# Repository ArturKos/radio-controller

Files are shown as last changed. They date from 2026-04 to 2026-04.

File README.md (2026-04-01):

# Radio Controller

A **433MHz RF light controller** built with an **ESP8266** (NodeMCU v2) and **CC1101** transceiver, managed through **ESPHome** and integrated with **Home Assistant**. Controls bedroom and living room lights over **ASK/OOK** modulation using captured RC Switch codes, with **Amazon Alexa** voice control via emulated_hue. Also functions as a passive **RF signal monitor**, logging all received 433MHz transmissions for discovering nearby weather stations, door sensors, and other devices. Includes a parametric **3D printable case** designed in **OpenSCAD**.








## Hardware

| NodeMCU v2 (ESP8266) | CC1101 RF Transceiver (433MHz) |
|:---:|:---:|
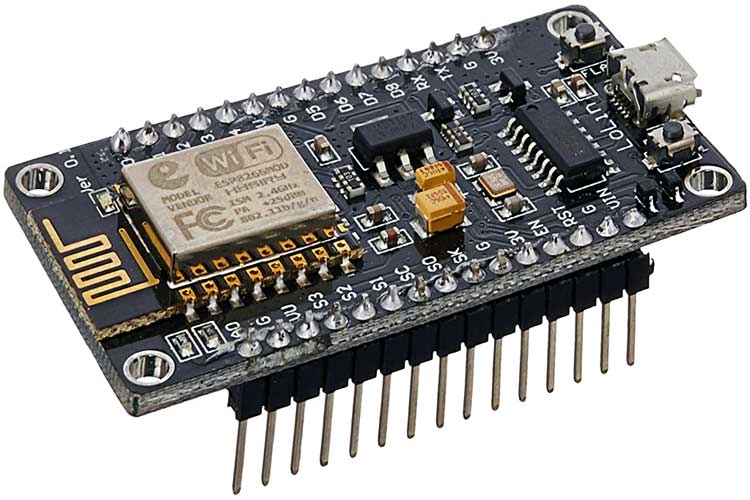
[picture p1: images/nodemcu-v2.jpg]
NodeMCU v2
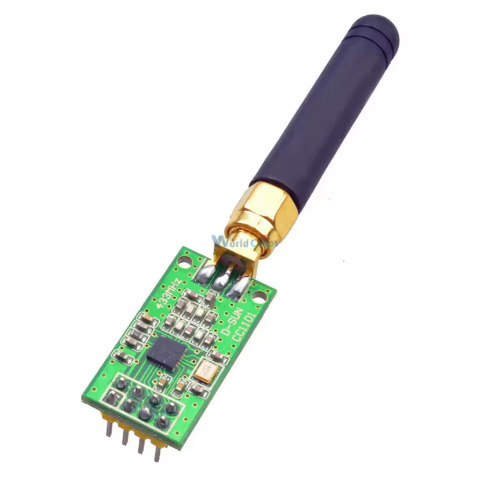
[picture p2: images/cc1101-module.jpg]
CC1101 Module
|  |  |

| Component | Details |
|---|---|
| MCU | NodeMCU ESP8266 v2 (nodemcuv2) |
| RF Transceiver | CC1101 with SMA antenna |
| Protocol | 433.92 MHz ASK/OOK |
| Integration | Home Assistant via ESPHome native API |
| Voice control | Amazon Alexa via emulated_hue |

## Wiring (SPI)

| CC1101 Pin | NodeMCU Pin | Function |
|---|---|---|
| SCK | D5 (GPIO14) | SPI Clock |
| MISO | D6 (GPIO12) | SPI Data Out |
| MOSI | D7 (GPIO13) | SPI Data In |
| CSN | D8 (GPIO15) | Chip Select |
| GDO0 | D2 (GPIO4) | RX + TX (shared) |
| GDO2 | D1 (GPIO5) | Connected, unused |
| VCC | 3.3V | Power (NOT 5V!) |
| GND | GND | Ground |

> **Note:** GDO0 is shared for both receiving and transmitting via `allow_other_uses: true`. The CC1101 native component switches between RX/TX modes automatically using `cc1101.begin_tx` / `cc1101.begin_rx` triggers.

## Features

- **Bedroom lights** (protocol 1) — Toggle, ON, OFF via HA buttons and Alexa voice commands
- **Living room lights** (protocol 3) — 8 buttons: toggle, on, off, timers (30s/30min/60min)
- **RF monitoring** — Counts received signals, logs all codes for device discovery
- **Noise filtering** — Protocol 2 code=0x0 spurious signals filtered out in lambda
- **WiFi hardening** — `fast_connect`, `power_save_mode: none`, max TX power for stable connection
- **3D printable case** — Parametric OpenSCAD enclosure with SMA antenna pass-through

## Architecture

```
┌──────────┐     SPI      ┌────────┐    433MHz    ┌──────────────┐
│ NodeMCU  │◄────────────►│ CC1101 │◄────────────►│ RF Lights    │
│ ESP8266  │              │  TX/RX │              │ (bedroom,    │
└────┬─────┘              └────────┘              │  living room)│
     │ WiFi                                       └──────────────┘
     ▼
┌──────────┐  emulated_hue  ┌───────┐
│  Home    │◄──────────────►│ Alexa │
│Assistant │                └───────┘
└──────────┘
```

## Setup

### 1. Prerequisites

- [ESPHome](https://esphome.io/) 2025.12.0+ (native CC1101 support)
- Home Assistant with ESPHome addon
- NodeMCU with ESPHome already flashed

### 2. Configure secrets

Copy and edit the secrets file:
```bash
cp secrets.yaml.example secrets.yaml
# Edit with your actual WiFi password, API key, etc.
```

### 3. Deploy

Upload config to HA and flash via ESPHome dashboard:
```bash
scp radio-controller.yaml ha:/homeassistant/esphome/radio-controller.yaml
```
Then open ESPHome dashboard in HA and click Install → Wirelessly.

### 4. Sniff RF codes

Open ESPHome logs and press buttons on your RF remotes. Look for entries like:
```
[rf_monitor] RC Switch: protocol=1 code=0x353FC0
```

### 5. Alexa integration

Bedroom lights are exposed via `emulated_hue` through `input_boolean.bedroom_light` in HA with automations that trigger the ESPHome button presses.

## RF Signal Discovery

The device logs all received 433MHz signals for identifying nearby devices (weather stations, door sensors, etc.):
- **Counter sensor** — "RF Signals Received" tracks daily activity (resets at midnight)
- **Last code sensor** — "Last RF Code" shows the most recent protocol + code
- Repeating codes every 30-60s are likely weather stations
- Codes appearing on events (door open/close) are likely contact sensors

## 3D Printed Case

Parametric OpenSCAD enclosure in `case/radio-controller-case.scad`. Fits NodeMCU v2 + CC1101 with SMA antenna.

| Assembled preview | Print layout (bottom + lid) |
|:---:|:---:|
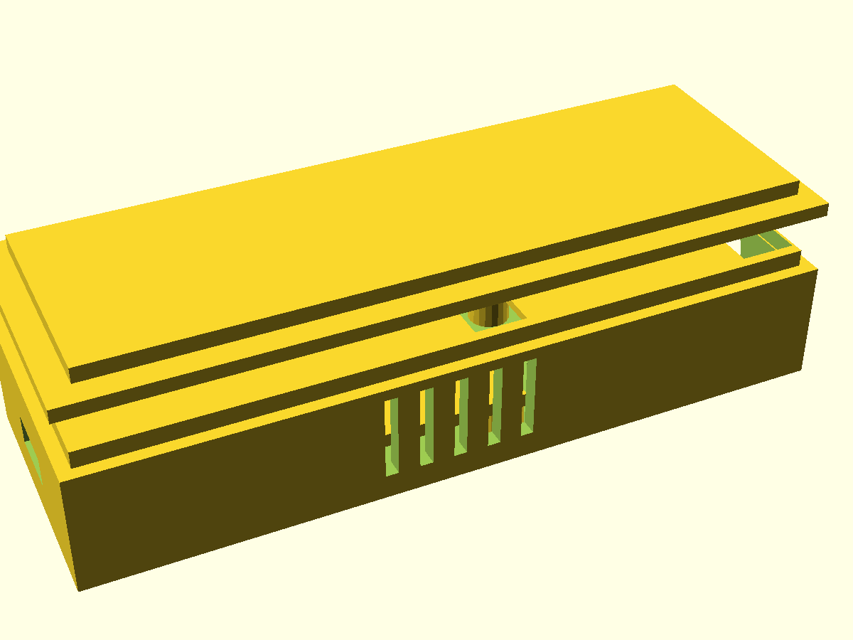
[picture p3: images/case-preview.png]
Case preview
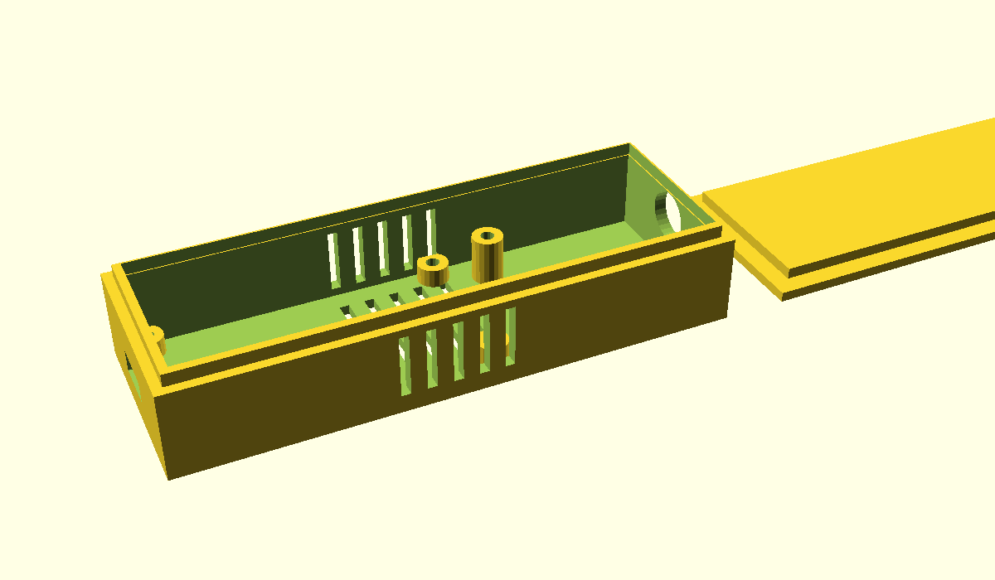
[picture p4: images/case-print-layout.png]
Print layout
|  |  |

- Mounting posts for both boards (M2 screws)
- Micro-USB cutout for power/programming
- SMA antenna hole for external antenna
- Snap-fit lid with alignment lip
- Ventilation slots on bottom, top, and sides
- No supports needed — print bottom and lid flat

Open in [OpenSCAD](https://openscad.org/), set `mode = "preview"` to see assembled view or `"print"` for print layout. Adjust `tol` parameter for your printer.

## Project Structure

```
radio-controller/
├── radio-controller.yaml          # ESPHome configuration
├── secrets.yaml                   # WiFi/API credentials (git-ignored)
├── case/
│   └── radio-controller-case.scad # 3D printable enclosure (OpenSCAD)
├── HOWTO.md                       # Development notes
└── README.md
```

## Known Issues

- **Living room lights** (protocol 3) — TX codes captured but lights don't respond; original remote also broken, likely receiver pairing issue
- **Protocol 2 noise** — RF interference generates ~2-3 spurious protocol 2 code=0x0 signals per minute; filtered in lambda
- **WiFi signal** — Marginal at -65 to -74 dBm; mitigated with `power_save_mode: none` and max TX power

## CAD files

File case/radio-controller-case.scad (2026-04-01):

// =============================================================================
// Radio Controller Case — NodeMCU v2 + CC1101 (SMA antenna)
// 3D printable enclosure, no supports needed
// Print: bottom + lid separately, flat side down
// =============================================================================

// --- Tolerances & print settings ---
tol       = 0.3;    // printer tolerance (adjust for your printer)
wall      = 2.0;    // wall thickness
floor_t   = 1.6;    // floor/ceiling thickness
post_d    = 5.0;    // mounting post diameter
screw_d   = 2.2;    // M2 screw hole diameter
snap_gap  = 0.2;    // lid snap-fit clearance

// --- NodeMCU v2 dimensions ---
nmc_l     = 49.0;   // length (USB to antenna end)
nmc_w     = 26.0;   // width
nmc_h     = 10.0;   // height with pins soldered underneath
nmc_pcb_t = 1.6;    // PCB thickness
nmc_usb_w = 8.0;    // micro-USB connector width
nmc_usb_h = 3.5;    // micro-USB connector height

// --- CC1101 module dimensions ---
cc_l      = 29.0;   // length (SMA end to opposite)
cc_w      = 20.0;   // width
cc_h      = 3.5;    // height (tallest component on PCB)
cc_pcb_t  = 1.0;    // PCB thickness
sma_d     = 6.5;    // SMA connector diameter (nut flats ~8mm)
sma_hole  = 8.0;    // SMA hole in wall (clearance for nut)

// --- Internal layout ---
gap       = 4.0;    // gap between NodeMCU and CC1101
wire_ch   = 3.0;    // wire channel depth

// --- Computed internal dimensions ---
int_l     = nmc_l + gap + cc_l + 2*tol;
int_w     = max(nmc_w, cc_w) + 2*tol;
int_h     = nmc_h + 2 + 2*tol;   // +2 for clearance above tallest component

// --- Computed external dimensions ---
ext_l     = int_l + 2*wall;
ext_w     = int_w + 2*wall;
ext_h_bot = floor_t + int_h;      // bottom half height
ext_h_lid = floor_t + 3;          // lid height (shallow)
lip_h     = 2.0;                  // lid inner lip height

// --- Vent hole settings ---
vent_w    = 1.5;
vent_gap  = 2.5;
vent_n    = 5;

// --- NodeMCU position (USB end at -X wall) ---
nmc_x     = wall + tol;
nmc_y     = wall + tol + (int_w - nmc_w)/2;

// --- CC1101 position (SMA end at +X wall) ---
cc_x      = wall + tol + nmc_l + gap;
cc_y      = wall + tol + (int_w - cc_w)/2;

// --- Mounting post positions ---
// NodeMCU: 4 corner posts, inset 2mm from edges
nmc_post_inset = 2.0;
nmc_posts = [
    [nmc_x + nmc_post_inset,               nmc_y + nmc_post_inset],
    [nmc_x + nmc_l - nmc_post_inset,       nmc_y + nmc_post_inset],
    [nmc_x + nmc_post_inset,               nmc_y + nmc_w - nmc_post_inset],
    [nmc_x + nmc_l - nmc_post_inset,       nmc_y + nmc_w - nmc_post_inset],
];

// CC1101: 2 posts on the non-SMA end
cc_post_inset = 2.0;
cc_posts = [
    [cc_x + cc_post_inset,                 cc_y + cc_post_inset],
    [cc_x + cc_post_inset,                 cc_y + cc_w - cc_post_inset],
];


// =============================================================================
// BOTTOM HALF
// =============================================================================
module bottom() {
    difference() {
        union() {
            // Main box
            difference() {
                // Outer shell
                cube([ext_l, ext_w, ext_h_bot]);

                // Inner cavity
                translate([wall, wall, floor_t])
                    cube([int_l, int_w, int_h + 1]);
            }

            // Mounting posts for NodeMCU
            for (p = nmc_posts) {
                translate([p[0], p[1], floor_t])
                    cylinder(d=post_d, h=3, $fn=20);
            }

            // Mounting posts for CC1101
            for (p = cc_posts) {
                translate([p[0], p[1], floor_t])
                    cylinder(d=post_d, h=nmc_h - cc_h + 1, $fn=20);
            }

            // Lid alignment rim (inner lip for lid to sit on)
            difference() {
                translate([wall - 0.5, wall - 0.5, ext_h_bot])
                    cube([int_l + 1, int_w + 1, lip_h]);
                translate([wall + 0.8, wall + 0.8, ext_h_bot - 0.1])
                    cube([int_l - 0.6, int_w - 0.6, lip_h + 0.2]);
            }
        }

        // --- Cutouts ---

        // Micro-USB port (NodeMCU, -X wall)
        translate([-0.1, nmc_y + nmc_w/2 - nmc_usb_w/2, floor_t + 3])
            cube([wall + 0.2, nmc_usb_w, nmc_usb_h]);

        // SMA antenna hole (CC1101, +X wall)
        translate([ext_l - wall - 0.1, cc_y + cc_w/2, floor_t + nmc_h - cc_h + cc_pcb_t + 1])
            rotate([0, 90, 0])
                cylinder(d=sma_hole, h=wall + 0.2, $fn=30);

        // Screw holes in mounting posts
        for (p = nmc_posts) {
            translate([p[0], p[1], -0.1])
                cylinder(d=screw_d, h=floor_t + 4, $fn=16);
        }
        for (p = cc_posts) {
            translate([p[0], p[1], -0.1])
                cylinder(d=screw_d, h=floor_t + nmc_h, $fn=16);
        }

        // Bottom ventilation slots
        translate([ext_l/2 - (vent_n*(vent_w + vent_gap))/2, ext_w/2 - 10, -0.1])
            for (i = [0:vent_n-1])
                translate([i * (vent_w + vent_gap), 0, 0])
                    cube([vent_w, 20, floor_t + 0.2]);

        // Side ventilation slots (both long sides)
        for (side = [0, ext_w - wall]) {
            translate([ext_l/2 - (vent_n*(vent_w + vent_gap))/2, side - 0.1, floor_t + int_h/2 - 5])
                for (i = [0:vent_n-1])
                    translate([i * (vent_w + vent_gap), 0, 0])
                        cube([vent_w, wall + 0.2, 10]);
        }

        // Round the top edges (cosmetic chamfer)
        // (skipped for printability — add fillets in slicer if desired)
    }
}


// =============================================================================
// LID
// =============================================================================
module lid() {
    difference() {
        union() {
            // Top plate
            cube([ext_l, ext_w, floor_t]);

            // Inner lip that fits inside the bottom rim
            translate([wall + 0.8 + snap_gap, wall + 0.8 + snap_gap, floor_t])
                cube([int_l - 0.6 - 2*snap_gap, int_w - 0.6 - 2*snap_gap, lip_h - 0.2]);
        }

        // Top ventilation slots
        translate([ext_l/2 - (vent_n*(vent_w + vent_gap))/2, ext_w/2 - 10, -0.1])
            for (i = [0:vent_n-1])
                translate([i * (vent_w + vent_gap), 0, 0])
                    cube([vent_w, 20, floor_t + 0.2]);

        // Label recess (optional: for a printed label)
        translate([ext_l/2 - 15, ext_w/2 - 5, -0.1])
            cube([30, 10, 0.4]);
    }
}


// =============================================================================
// ASSEMBLY PREVIEW / PRINT LAYOUT
// =============================================================================

// Set to "preview" to see assembled, "print" for print layout
mode = "print";  // "preview" or "print"

if (mode == "preview") {
    // Assembled view
    color("DarkSlateGray") bottom();
    color("SlateGray", 0.5) translate([0, 0, ext_h_bot + lip_h + 5])
        lid();

    // Ghost boards for reference
    color("green", 0.3) translate([nmc_x, nmc_y, floor_t + 3])
        cube([nmc_l, nmc_w, nmc_pcb_t]);
    color("green", 0.3) translate([cc_x, cc_y, floor_t + nmc_h - cc_h + 1])
        cube([cc_l, cc_w, cc_pcb_t]);

} else {
    // Print layout — both parts flat, side by side
    bottom();
    translate([ext_l + 10, 0, 0])
        lid();
}


// =============================================================================
// DIMENSIONS (for reference)
// =============================================================================
// Uncomment to print dimensions to console:
// echo(str("External: ", ext_l, " x ", ext_w, " x ", ext_h_bot + floor_t + lip_h, " mm"));
// echo(str("Internal: ", int_l, " x ", int_w, " x ", int_h, " mm"));
// echo(str("Lid height: ", ext_h_lid, " mm"));

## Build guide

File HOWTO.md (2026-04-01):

# RF 433MHz Radio Controller — HOWTO

## Overview

Control 433MHz RF lights in bedroom and living room from Home Assistant and Alexa using ESP8266 (NodeMCU) + CC1101 transceiver via ESPHome. Also monitors all 433MHz RF activity (weather stations, door sensors, remotes).

## Hardware

- NodeMCU ESP8266 (board: nodemcuv2)
- CC1101 433MHz transceiver module (SMA antenna)
- Breadboard + jumper wires

## Wiring

```
CC1101          NodeMCU
──────          ───────
VCC      ────►  3.3V  (NOT 5V!)
GND      ────►  GND
SCK      ────►  D5  (GPIO14)
MISO     ────►  D6  (GPIO12)
MOSI     ────►  D7  (GPIO13)
CSN      ────►  D8  (GPIO15)
GDO0     ────►  D2  (GPIO4)   ← shared RX/TX pin
GDO2     ────►  D1  (GPIO5)   ← connected but unused currently
```

**Important:**
- CC1101 is **3.3V only** — 5V will damage it
- GDO0 (D2) handles both receiving and transmitting — the CC1101 switches modes via `cc1101.begin_tx` / `cc1101.begin_rx` triggers
- If Chip ID shows `0xFFFF` → SPI wiring is wrong or loose

## How It Works

```
┌──────────┐     SPI      ┌────────┐    433MHz    ┌──────────┐
│ NodeMCU  │◄────────────►│ CC1101 │◄────────────►│ RF Lights│
│ ESP8266  │              │  TX/RX │              │ (bedroom)│
└────┬─────┘              └────────┘              └──────────┘
     │ WiFi                                    ┌──────────────┐
     ▼                                         │Weather stations│
┌──────────┐                                   │Door sensors    │
│  Home    │  ◄── Alexa (emulated_hue)         │Other 433MHz   │
│Assistant │                                   └──────────────┘
└──────────┘
```

## Button Mapping

### Bedroom (Remote 1 — rc_switch protocol 1) ✅ Working

| Button | Function | Code |
|---|---|---|
| 1 | Toggle on/off | `001101010011111111000000` |
| 2 | Toggle on/off | `001101010011111100110000` |
| 3 | ON | `001101010011111100001100` |
| 4 | OFF | `001101010011111100000011` |

### Living Room (Remote 2 — rc_switch protocol 3) ❌ Not working

| Button | Function | Code |
|---|---|---|
| 1 | Toggle on/off | `000100011111101100010000` |
| 2 | Toggle on/off | `000100011111101100100000` |
| 3 | OFF | `000100011111101111100000` |
| 4 | ON | `000100011111101111000000` |
| 5 | OFF | `000100011111101101100000` |
| 6 | Timer 30s | `000100011111101101000000` |
| 7 | Timer 30min | `000100011111101110100000` |
| 8 | Timer 60min | `000100011111101110000000` |

Note: Living room codes were sniffed successfully but TX doesn't trigger the lights. Original remote also stopped working — may be a pairing issue.

## Setup

### 1. Flash ESPHome

First time (USB):
```bash
esphome run radio-controller.yaml
# Select USB/serial port
```

Update (OTA — device already running ESPHome):
```bash
esphome run radio-controller.yaml
# Select OTA / 192.168.1.172
```

Or use ESPHome dashboard: **HA → ESPHome → radio-controller → INSTALL → Wirelessly**

### 2. Verify CC1101

Check logs for:
```
[C][cc1101:224]: CC1101:
[C][cc1101:224]:   Chip ID: 0x0014       ← CC1101 detected
```

### 3. Alexa Integration

The bedroom light is exposed to Alexa via emulated_hue:
- **"Alexa, turn on bedroom light"**
- **"Alexa, turn off bedroom light"**

How it works:
1. `input_boolean.bedroom_light` — virtual switch in HA
2. Automation watches the boolean → presses ESPHome button (ON or OFF)
3. `emulated_hue` exposes the boolean to Alexa as "Bedroom light"

If Alexa doesn't see the device, say **"Alexa, discover devices"**.

### 4. RF Activity Monitoring

The device continuously listens for all 433MHz signals. In Home Assistant:
- **RF Signals Received** — counter of signals caught (resets at midnight)
- **Last RF Code** — protocol + hex code of last received signal
- **ESPHome Logs** — detailed view of all received codes

#### Discovering Devices

1. Open **ESPHome → Logs** for radio-controller
2. Watch for repeating codes:
   - Every 30-60s → likely a **weather station**
   - On door open/close → **door/window sensor**
   - Random bursts → other remotes, car key fobs, etc.
3. Note the protocol and hex code from logs

#### Adding Door/Window Sensors

After identifying a sensor's codes, edit the YAML:

1. Uncomment the `binary_sensor` template for `front_door`
2. Add the sensor's open/close codes to the `on_rc_switch` lambda:
```cpp
if (x.protocol == 1 && x.code == 0xYOUR_OPEN_CODE) {
  id(door_sensor_1_state) = true;
  id(front_door).publish_state(true);
}
if (x.protocol == 1 && x.code == 0xYOUR_CLOSE_CODE) {
  id(door_sensor_1_state) = false;
  id(front_door).publish_state(false);
}
```

### 5. Sniff New Remote Codes

To capture codes from a new remote, temporarily change dump mode:
```yaml
remote_receiver:
  dump: all          # change from rc_switch to all
  filter: 50us       # reduce from 200us
  idle: 10ms         # increase from 4ms
  buffer_size: 2048  # add this line
```

Flash, open logs, press remote buttons, note the codes. Then revert settings.

## Key Technical Notes

- **CC1101 mode switching is critical:** The `on_transmit: cc1101.begin_tx` and `on_complete: cc1101.begin_rx` triggers in `remote_transmitter` are what make TX work. Without them, the CC1101 stays in RX mode and transmitting silently fails.
- **Single pin for RX+TX:** Both `remote_receiver` and `remote_transmitter` share GDO0 (D2) with `allow_other_uses: true`. The CC1101 component handles mode switching.
- **Board must be `nodemcuv2`:** Using `esp01_1m` causes "Cannot resolve pin name" errors for D-pin aliases.
- **Lambda types:** `x.code` in `on_rc_switch` is `uint64_t`, not string. Use `%llX` format.
- **dbuezas external component is dead:** Broken since ESPHome 2025.2. Use the native `cc1101:` component (available since ESPHome 2025.12.0).

## Troubleshooting

| Problem | Solution |
|---|---|
| Chip ID: 0xFFFF | SPI wiring wrong or loose. Check all wires. Verify 3.3V power. |
| No codes when pressing remote | Check GDO0→D2 wire. Press remote close to antenna. Use `dump: all`. |
| Codes sniffed but TX doesn't work | Check `on_transmit: cc1101.begin_tx` trigger exists. Increase `repeat: times:`. |
| "Cannot resolve pin name" | Change board from `esp01_1m` to `nodemcuv2`. |
| Compilation error on x.code.c_str() | `x.code` is uint64_t — use `%llX` format, not `.c_str()`. |
| Alexa doesn't find device | Say "Alexa, discover devices". Check emulated_hue config in HA. |
| OTA upload fails | Check WiFi. Use USB as fallback. |
| Boot loop | Hold FLASH button during boot → safe mode. Re-flash via USB. |

## Files

| File | Purpose |
|---|---|
| `radio-controller.yaml` | ESPHome config (CC1101 + RF RX/TX + 12 buttons + monitoring sensors) |
| `secrets.yaml` | WiFi password, API key, OTA password (git-ignored) |
| `.gitignore` | Excludes secrets and .esphome cache |

## HA Configuration Changes

These entries were added to the Home Assistant server (192.168.1.142):

- **configuration.yaml:** `input_boolean.bedroom_light` + `emulated_hue` entry
- **automations.yaml:** Two automations — bedroom light on/off via RF button press

## Technology Stack

- **ESPHome** 2026.3.1 (native CC1101 component)
- **Home Assistant** (API integration + emulated_hue for Alexa)
- **CC1101** TI sub-GHz transceiver (SPI, 433.92MHz ASK/OOK)
- **ESP8266** NodeMCU (WiFi, hostname: radio-controller, IP: 192.168.1.172)
- **Alexa** voice control via emulated_hue bridge

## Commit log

2026-04-01 Initial commit: ESP8266 + CC1101 433MHz RF light controller
    ESPHome-based radio controller for bedroom and living room lights via
    Home Assistant with Alexa voice control. Includes RF signal monitoring,
    noise filtering, parametric OpenSCAD 3D printable case, and hardware images.
    [radio-controller-case.scad, radio-controller.yaml]
2026-04-28 Replace CC1101 module photo
    Use a clearer studio shot of the CC1101 with stubby SMA antenna
    (former image was a stock photo with watermark).

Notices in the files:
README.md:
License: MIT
